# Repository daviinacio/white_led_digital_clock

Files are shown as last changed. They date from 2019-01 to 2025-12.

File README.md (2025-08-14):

# White Led Digital Clock

A digital clock made by scratch. Initially built with cardboard, it was re-assembled with 3D-printed parts. It also received hardware and software improvements. Its based on Arduino UNO microcontroller, assembled in a custom standalone PCB.

| | |
| :---: | :---: |
|  |  |

## Dependencies

- [Arduino Thread](https://github.com/ivanseidel/ArduinoThread)
- [arduino-buffer](https://github.com/daviinacio/arduino-buffer)
- [RTClib](https://github.com/adafruit/RTClib)
- [DHT Sensor Library](https://github.com/adafruit/DHT-sensor-library)
- [Arduino-IRremote](https://github.com/z3t0/Arduino-IRremote)
- [EEPROMEx](https://github.com/thijse/Arduino-EEPROMEx)

## Hardware

- Custom electronic board
- RTC (Real Time Clock)
- DHT (Temperature and Humidity Sensor)
- LDR (Light Dependent Resistor
- IR (Infra Red Receiver)
- Lithium battery
- Buzzer

## Features

- Show the current time
- Show the average of temperature and humidity
- Changes the display brightness automatically
- Can be controlled by TV remote control
- Time adjust
- Adjustable RTC Time Fix

## Files and Images

### Principal files

- [firmware.ino](https://github.com/daviinacio/White_Led_Digital_Clock/blob/master/firmware/firmware.ino)

### Schematic design and PCB prints

|                       Schematic design                        |
| :-----------------------------------------------------------: |
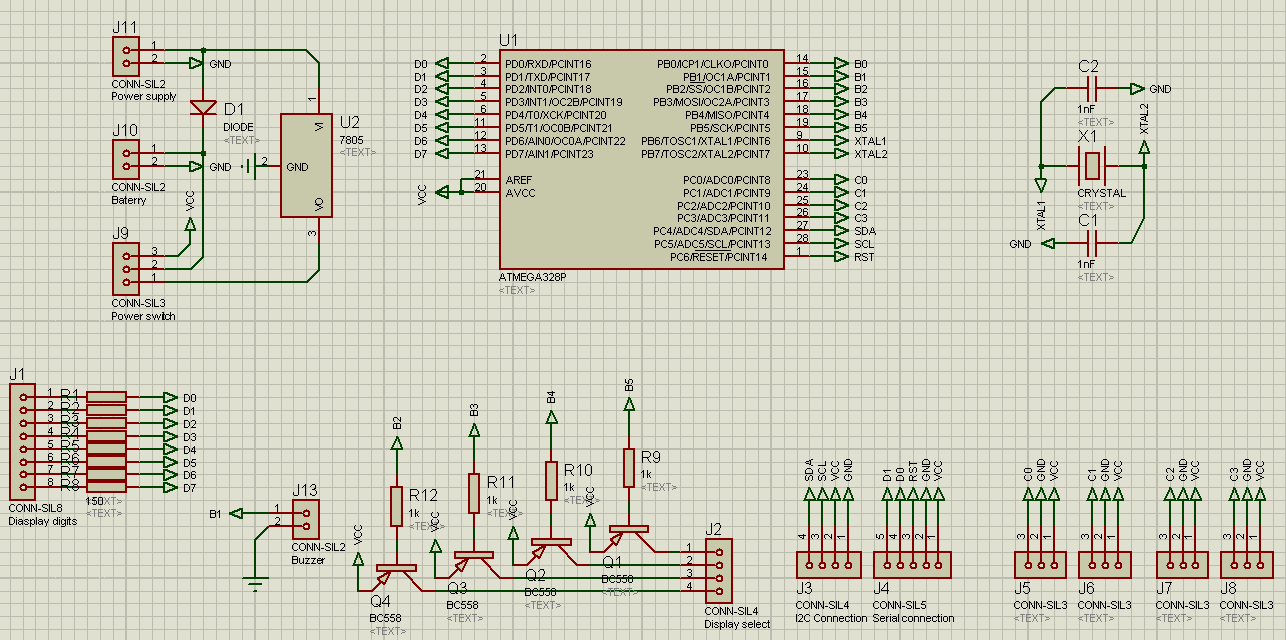
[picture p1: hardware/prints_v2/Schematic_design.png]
Schematic design
|  |

| PCB layout | PCB preview |
| :---: | :---: |
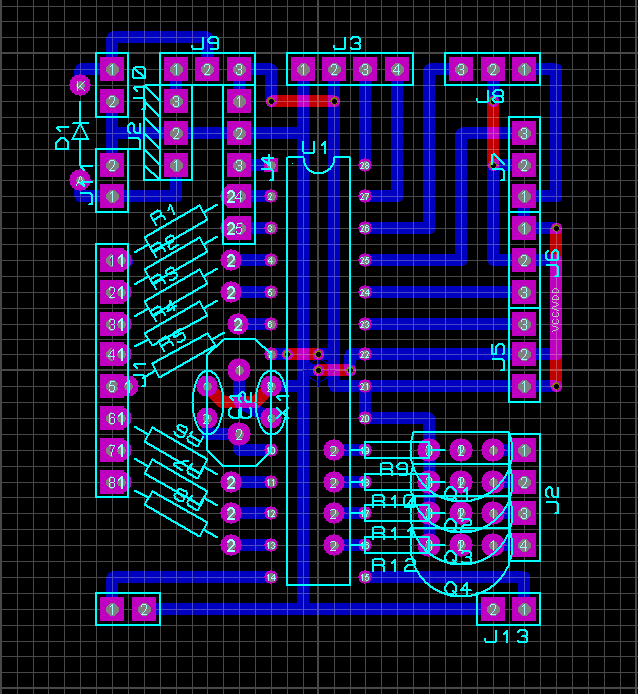
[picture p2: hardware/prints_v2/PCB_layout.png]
PCB layout
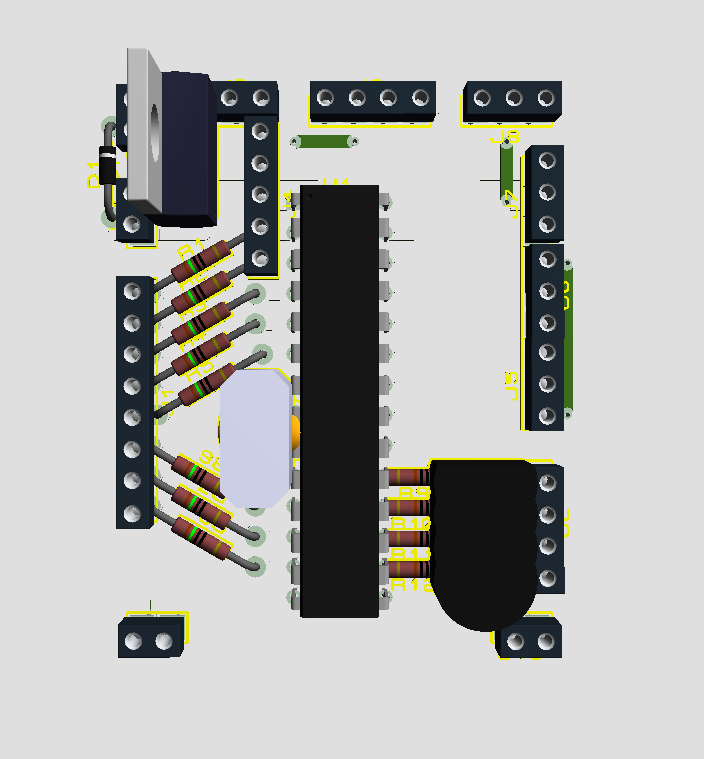
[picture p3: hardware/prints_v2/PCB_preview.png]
PCB preview
|  |  |

### More Photos

| | | |
| :---: | :---: | :---: |
|  |  |  |

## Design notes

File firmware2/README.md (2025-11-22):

# White Led Digital Clock : Firmware v2

## Commands

**Compile**

```bash
pio run
```

**Upload**

```bash
pio run --target upload
```

```bash
pio run -t upload -e <env_name>
```

```bash
pio run -t upload -e uno
```

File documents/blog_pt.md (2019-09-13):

# White Led Digital Clock
#### 01 de maio de 2019

#### OBS: As especificações do projeto podem ser modificadas no futuro.

A estrutura desse projeto foi feita com papelão e sucata.
---------------------------------------------------------------------------------------------------
## Software
- [Firmware](https://github.com/daviinacio/White_Led_Digital_Clock/blob/master/firmware/firmware.ino)

### Dependências
- [Arduino Thread](https://github.com/ivanseidel/ArduinoThread)
- [arduino-buffer](https://github.com/daviinacio/arduino-buffer)
- [RTClib](https://github.com/adafruit/RTClib)
- [Arduino-IRremote](https://github.com/z3t0/Arduino-IRremote)
---------------------------------------------------------------------------------------------------
## Hardware
- Papelão
- Painel Difusor de TV led (Ou qualquer superfície semi-transparente)
- Cola-quente
- Fita crepe
- Fita isolante
- Fita dupla-face

### Fixação
-  2x Porca (#1)
-  4x Porca (#2)
-  2x Parafuso(#1)
-  1x Barra rosqueada (#2)
-  4x Arruela (#1)
-  8x Arruela (#2)

### Componentes Eletrônicos
- 28x [Led SMD Branco 0.5W](http://www.institutodigital.com.br/pd-31c54f-led-smd-branco-0-5w-40-65lm-mod-5730.html)
-  1x [Atmega 328p](http://www.institutodigital.com.br/pd-5666bf-microcontrolador-atmega328p-pu.html)
-  1x [Cristal Ocilador 16MHz](https://www.soldafria.com.br/cristal-16-mhz-meia-caneca-hc49s-p-1940.html)
-  2x [Capacitor cerâmico 22pF](https://www.soldafria.com.br/capacitor-disco-ceramico-22pf-x-50v-npo)
-  8x [Resistor 1/4W 75r](https://www.soldafria.com.br/resistor-de-75r-carbono-5-14w-rxvdptdr-p-112.html)
-  4x [Resistor 1/4W 1k2](https://www.soldafria.com.br/resistor-de-1k2-carbono-5-14w-mrvmvmdr-p-141.html)
-  4x [Transistor BC548](https://www.soldafria.com.br/transistor-bc548b)
-  2x [Barra de pinos 1x40 vias 90 graus](https://www.soldafria.com.br/barra-de-pinos-1x40-vias-17mm-90-graus-p-4033.html)
-  1x [Diodo 1N4007](https://www.soldafria.com.br/diodo-1n4007)
-  1x [LM7805](https://www.soldafria.com.br/circuito-integrado-lm7805-p-557.html)
-  1x [LDR 5mm](http://www.institutodigital.com.br/pd-182de8-sensor-fotoresistor-ldr-5528-de-5mm.html)
-  1x [Receptor Infravermelho](http://www.institutodigital.com.br/pd-182dbd-receptor-universal-infravermelho-vs1838b-38khz.html)
-  1x [Buzzer 5v Ativo](http://www.institutodigital.com.br/pd-2d108d-buzzer-5-volts-ativo.html)
-  1x [Jack J4 DC-005](https://www.soldafria.com.br/jack-j4-dc-005-p-placa-25mm-x-55mm-p-748.html)

### Módulos
- [DHT11](http://www.institutodigital.com.br/pd-f5840-sensor-de-umidade-e-temperatura-dht11.html)
- [RTC DS1307](http://www.institutodigital.com.br/pd-f660a-modulo-real-time-clock-rtc-ds1307.html)

### Adicional
- Bateria de lithium 3.7v
---------------------------------------------------------------------------------------------------
## Contrução

### 1 - Defina as dimensões do display
|Calculos das dimensões|
|----------------------|
||

- 1.1 Baixe e imprima o [modelo de display 7 segmentos](https://github.com/daviinacio/White_Led_Digital_Clock/blob/master/documents/7%20Segment%20Display%20model%20(16cm%20x%208cm).docx)
- 1.2 Una as partes do modelo simetricamente

### 2 - Monte a parte fronta do display
|Calculos das dimensões|
|----------------------|
||

- 2.1 Faça a marcação no papelão à partir do modelo
- 2.2 Corte papelão e fixe o formato com fita crepe

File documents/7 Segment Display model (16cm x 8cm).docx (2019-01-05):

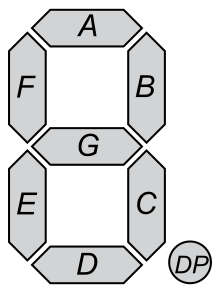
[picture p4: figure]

]b

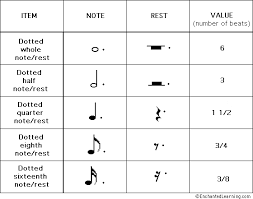
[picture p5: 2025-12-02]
documents/images.png

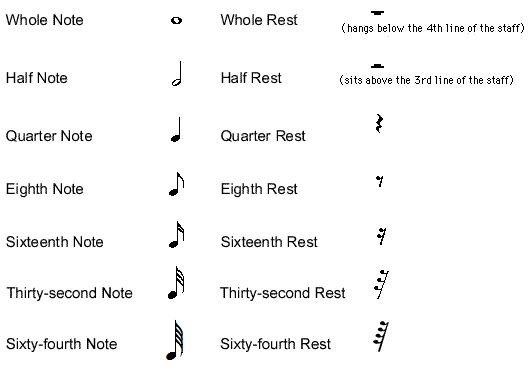
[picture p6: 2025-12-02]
documents/a3cd8b3504482aad7ffb78c6925b5304.jpg

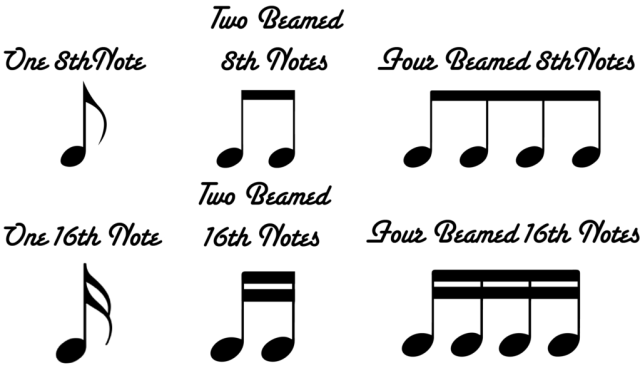
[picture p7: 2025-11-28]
documents/Difference-Between-8th-notes-and-16th-notes-1024x588.webp

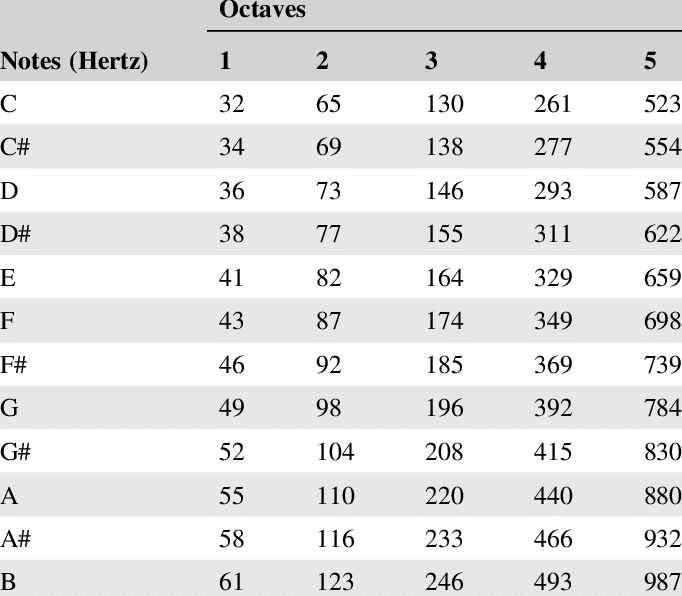
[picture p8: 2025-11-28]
documents/Frequencies-of-musical-notes (1).png

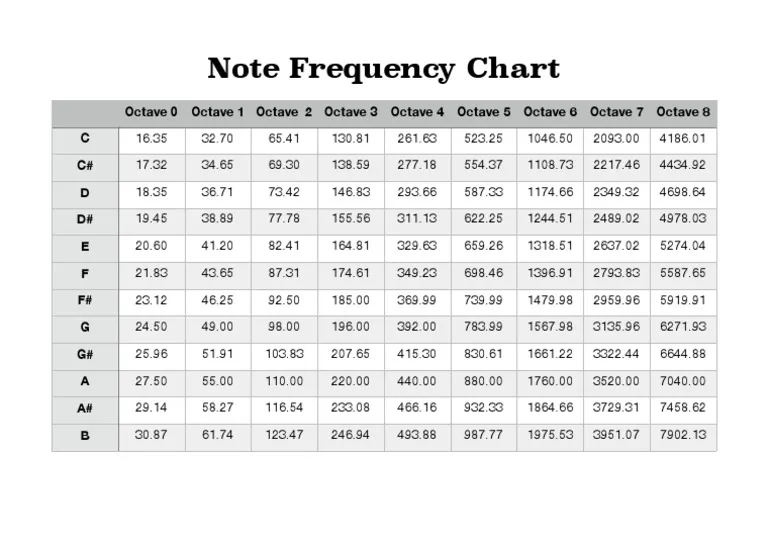
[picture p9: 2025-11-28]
documents/Frequencies-of-musical-notes (2).webp

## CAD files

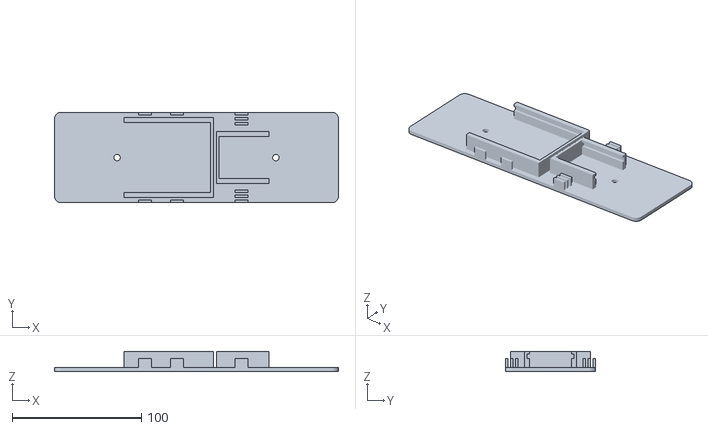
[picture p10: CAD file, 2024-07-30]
3d models/Circuit Platform.stl
220.0 x 70.0 x 15.5

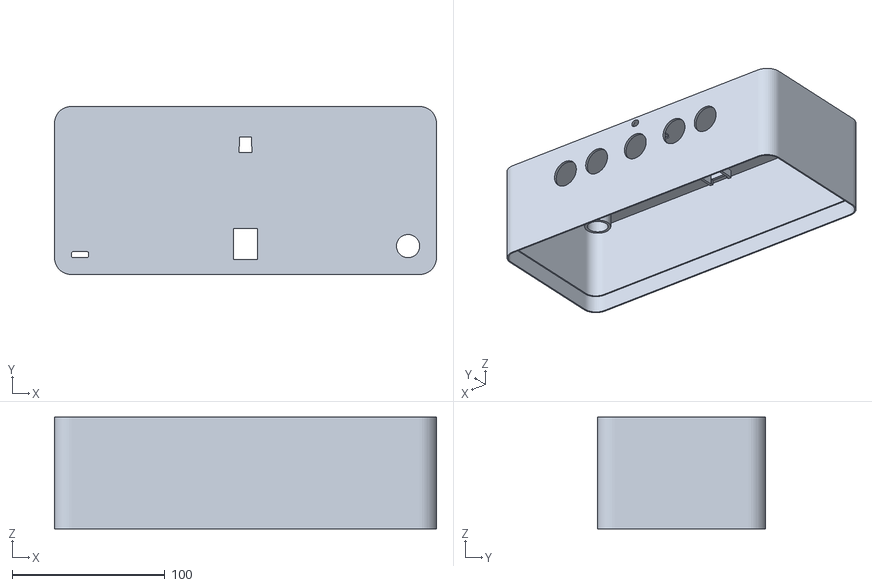
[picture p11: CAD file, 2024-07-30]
3d models/Case.stl
250.0 x 110.0 x 73.0

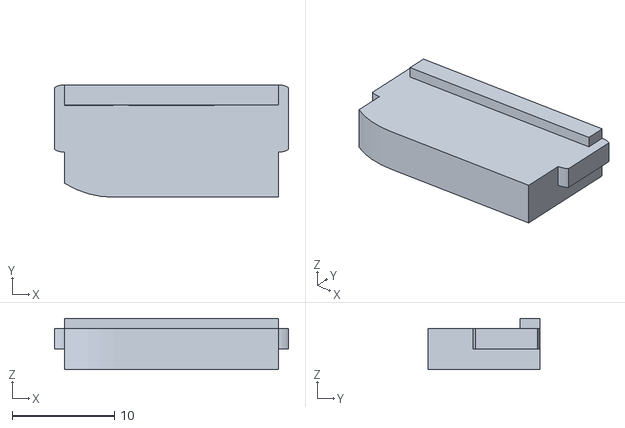
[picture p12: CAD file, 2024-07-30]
3d models/USB-C Slot Lock.stl
22.9 x 11.0 x 5.00

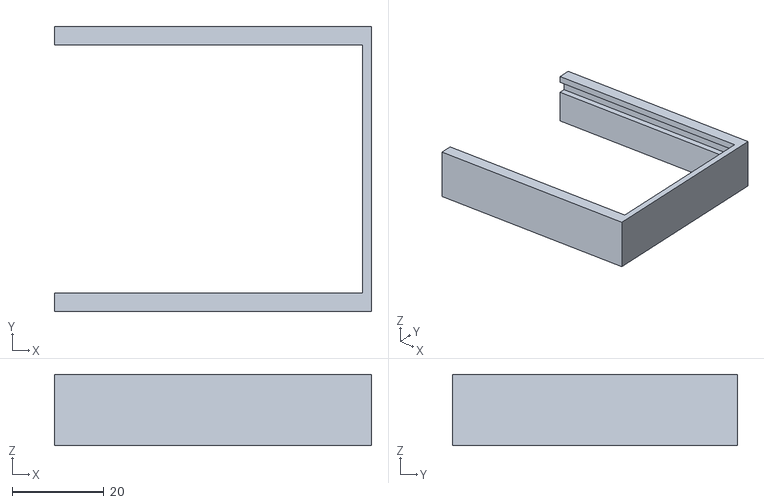
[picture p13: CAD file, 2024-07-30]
3d models/Circuit Platform Supports.stl
69.0 x 62.0 x 15.5

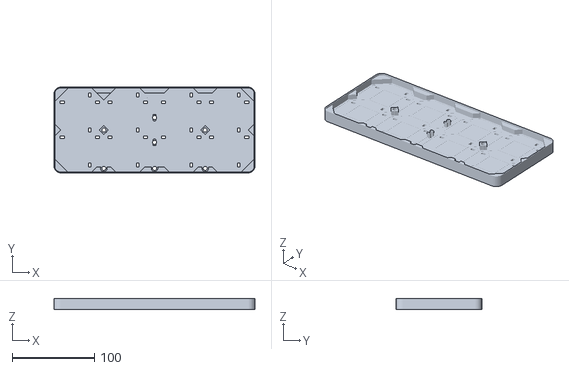
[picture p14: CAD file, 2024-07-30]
3d models/Backlight Front.stl
244.0 x 104.0 x 13.0

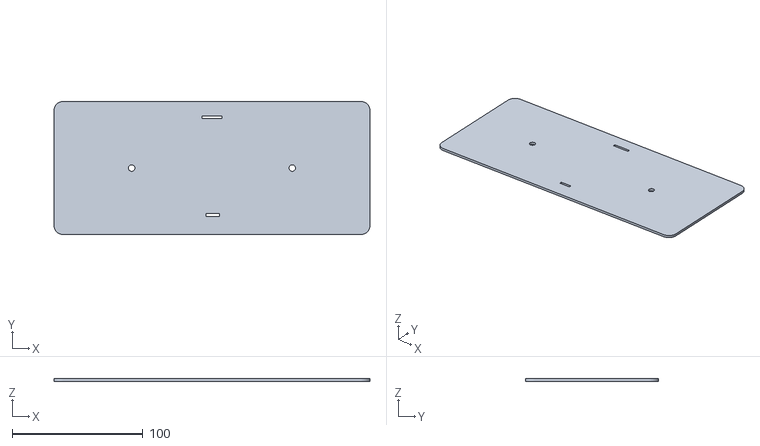
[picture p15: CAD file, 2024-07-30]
3d models/Backlight Back.stl
242.0 x 102.0 x 2.00

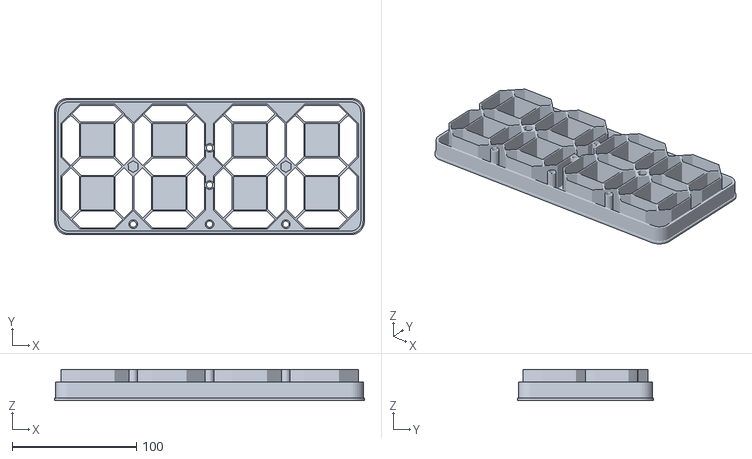
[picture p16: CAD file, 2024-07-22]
3d models/Display.stl
250.0 x 110.0 x 25.0

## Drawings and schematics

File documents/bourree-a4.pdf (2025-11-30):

p

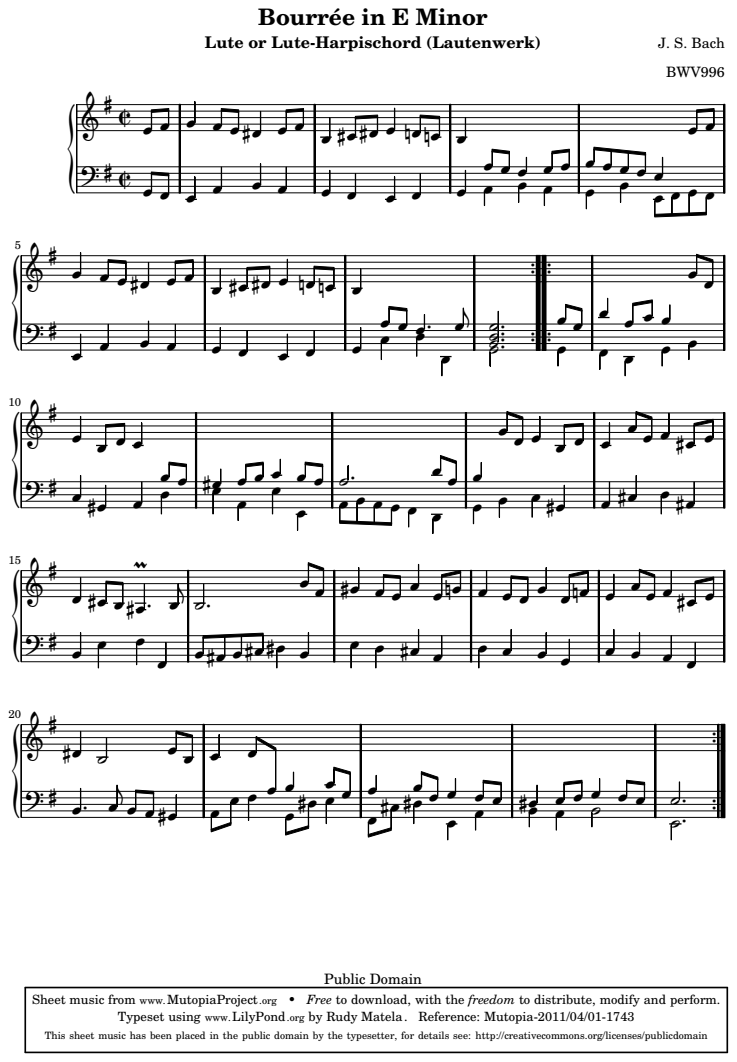
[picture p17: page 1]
Bourrée in E Minor; Lute or Lute-Harpischord (Lautenwerk); J. S. Bach; BWV996; Public Domain

P |    | P

Sheet music from www.MutopiaProject.org • Free to download, with the freedom to distribute, modify and perform.

Typeset using www.LilyPond.org by Rudy Matela. Reference: Mutopia-2011/04/01-1743

This sheet music has been placed in the public domain by the typesetter, for details see: http://creativecommons.org/licenses/publicdomain

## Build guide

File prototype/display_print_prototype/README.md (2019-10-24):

### Compile log before update
```bash
Sketch uses 13828 bytes (42%) of program storage space. Maximum is 32256 bytes.
Global variables use 725 bytes (35%) of dynamic memory, leaving 1323 bytes for local variables. Maximum is 2048 bytes.
```

### Compile log after update
```bash
Sketch uses 13968 bytes (43%) of program storage space. Maximum is 32256 bytes.
Global variables use 780 bytes (38%) of dynamic memory, leaving 1268 bytes for local variables. Maximum is 2048 bytes.
```

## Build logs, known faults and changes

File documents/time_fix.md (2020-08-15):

# Time increase fix
daviinacio | 11/03/2020

## Getting information
> Before check
20h17	20h20	> 3min

> Clock changes
20h18	20h20	> 2min

		26s		> Interval between changes

> Real time changes
20h18	20h21	> 2m26s

Increased 146 seconds in 11 days and 286 seconds (967560 seconds or 967560000 milliseconds)

## Interval calc
```
/* Time in milliseconds */

increased = 146000; 
period = 967560000;

interval = increased / period;

// interval = 6627
```

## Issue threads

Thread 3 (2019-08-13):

Refactor the chronometer display algorithm

daviinacio, 2019-08-13:
The pow functions brake a lot the time machine.
Reducing the call to this function, the code will runs more efficiently.

Change this:
``` C
case MAIN_SCREEN_CHRONOMETER:
  // Put the last digits of number on the display content array
  for(int i = 0; i < DISP_LENGTH; i++)
  disp_content[i] = ((chronometer_counter / (int) pow(10, DISP_LENGTH - i - 1)) % 10) > 0 || chronometer_counter >= (int) pow(10, DISP_LENGTH - i) || (chronometer_counter == 0 && i == DISP_LENGTH - 1) ? seven_seg_numbers[(chronometer_counter / (int) pow(10, DISP_LENGTH - i - 1)) % 10] : 0x00;
  break;
```

To
``` C
case MAIN_SCREEN_CHRONOMETER:
  // Put the last digits of number on the display content array
  for(int i = 0; i < DISP_LENGTH; i++){
    int power = (int) pow(10, DISP_LENGTH - i - 1);
    disp_content[i] = ((chronometer_counter / power) % 10) > 0 || chronometer_counter >= (power * 10) || (chronometer_counter == 0 && i == DISP_LENGTH - 1) ? seven_seg_numbers[(chronometer_counter / power) % 10] : 0x00;
  }
  break;
```

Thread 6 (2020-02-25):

Time increasing on wrong speed

daviinacio, 2020-02-25:
#Time increasing seven seconds everyday.

## Try to solve
- Make a thread to back seven seconds each 24h or one seconds each 3/5 hours
- Seach to hardware fix

Closed 2020-08-15.

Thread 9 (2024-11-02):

Fix panel multiple clicks programmatically.

daviinacio, 2024-11-02:
**Problems**
- The buttons are been presses many time on a single pressing.
- Sometimes, it are reading different button on a single pressing because of button resistance.

**Solutions**
- [ ] Implement a could down after release a button.
- [ ] Ignore if pressing another button without releasing the previous one.

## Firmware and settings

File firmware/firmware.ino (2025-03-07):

/*
 * (c) daviapps 2020
 * 
 * White LED Digital Clock 
 * 
 * description: This is the firmware of a led digital clock (7 segments)
 * author: github.com/daviinacio
 * date: 16/01/2019
 * 
 */

// Disables multiplex display, and enables Serial print
bool debug_mode = false;

#define WAKE_PIN A1

#define LDR_PIN A2
#define LDR_MIN 0
#define LDR_MAX 650

#define DISP_BR_MIN 1
#define DISP_BR_MAX 64

#define DISP_BR_BUFFER_LENGTH 16
#define DISP_BR_BUFFER_INTERVAL 2000
#define DISP_BRINK_INTERVAL 300

#define MAIN_INTERVAL 100
#define MAIN_SCREEN_HOME 0x00
#define MAIN_SCREEN_CHRONOMETER 0x01
#define MAIN_SCREEN_LDR 0x02
#define MAIN_SCREEN_ADJUST_TIME 0x03
#define MAIN_SCREEN_ADJUST_RTC_FIX 0x04

#define MAIN_SCREEN_FIRST MAIN_SCREEN_CHRONOMETER
#define MAIN_SCREEN_LAST MAIN_SCREEN_ADJUST_RTC_FIX

#define CHRONOMETER_INTERVAL 100

#define RTC_INTERVAL 1000

#define DHT_INIT_VALUE -255
#define DHT_PIN A0
#define DHT_TYPE DHT11
#define DHT_BUFFER_LENGTH 4
#define DHT_BUFFER_INTERVAL 60000

#define IR_PIN A1
#define IR_INTERVAL 200

#define BZ_PIN PB1
#define BZ_INTERVAL 62
#define BZ_STATUS_OFF 0x00
#define BZ_STATUS_OLDCLOCK 0x01

#define PANEL_PIN A3
#define PANEL_INTERVAL 100
#define PANEL_LONG_PRESS 8

#define ADJUST_TIME_CURSOR_RANGE 5
#define ADJUST_RTC_FIX_CURSOR_RANGE 2

#define RTC_FIX_INTERVAL_EEPROM_ADDRESS 0x05
#define RTC_FIX_OPERATION_EEPROM_ADDRESS 0x01

// Library imports
#include <EEPROMex.h>
#include <Thread.h>
#include <ThreadController.h>
#include <Wire.h>
#include <avr/sleep.h>

#include "RTClib.h"
#include "DHT.h"

// Import Modules
#include "display.hpp"
#include "panel.hpp"
#include "infrared.hpp"
#include "utils.hpp"
#include "buffer.hpp"

// Modules
AnalogPanel panel = AnalogPanel(PANEL_PIN, PANEL_INTERVAL);
InfraredSensor ir = InfraredSensor(IR_PIN);
// LightSensor ldr = LightSensor(LDR_PIN);


// Threads
ThreadController cpu = ThreadController();
Thread thr_main = Thread();
Thread thr_chronometer = Thread();

Thread thr_ldr = Thread();
Thread thr_rtc = Thread();
Thread thr_dht = Thread();
// Thread thr_ir = Thread();
Thread thr_buzzer = Thread();
Thread thr_rtc_fix = Thread();

Buffer disp_brightness_buffer(DISP_BR_BUFFER_LENGTH, DISP_BR_MAX);

// RTC
RTC_DS1307 rtc;
DateTime rtc_now;

// DHT
DHT dht(DHT_PIN, DHT_TYPE);

Buffer dht_temp_buffer(DHT_BUFFER_LENGTH, DHT_INIT_VALUE);
Buffer dht_hum_buffer(DHT_BUFFER_LENGTH, DHT_INIT_VALUE);

// Main
unsigned short main_current_screen = MAIN_SCREEN_HOME;
unsigned short main_cursor = 0;
bool main_cursor_blink = false;

// Chronometer
unsigned int chronometer_counter = 0;

// Buzzer
unsigned short buzzer_status = BZ_STATUS_OFF;

// RTC Fix
unsigned short rtc_fix_interval = 1;
unsigned short rtc_fix_operation = 1;

// Time Adjust
unsigned short time_adjust_year = 0;
unsigned short time_adjust_month = 0;
unsigned short time_adjust_day = 0;
unsigned short time_adjust_hour = 0;
unsigned short time_adjust_minute = 0;
unsigned short time_adjust_second = 0;

DateTime rtc_adjust;

void setup() {
  /*    *    *  THREADS  *    *    */

  // ldr.onRun(Display.run());

  // Initialize threads
  thr_main.onRun(thr_main_func);
  thr_main.setInterval(MAIN_INTERVAL);

  thr_chronometer.onRun(thr_chronometer_func);
  thr_chronometer.setInterval(CHRONOMETER_INTERVAL);
  thr_chronometer.enabled = false;

  thr_ldr.onRun(thr_ldr_func);
  thr_ldr.setInterval(DISP_BR_BUFFER_INTERVAL / DISP_BR_BUFFER_LENGTH);

  thr_rtc.onRun(thr_rtc_func);
  thr_rtc.setInterval(RTC_INTERVAL);

  thr_dht.onRun(thr_dht_func);
  thr_dht.setInterval(DHT_BUFFER_INTERVAL / DHT_BUFFER_LENGTH);

  // thr_ir.onRun(thr_ir_func);
  // thr_ir.setInterval(IR_INTERVAL);

  thr_buzzer.onRun(thr_buzzer_func);
  thr_buzzer.setInterval(BZ_INTERVAL);

  thr_rtc_fix.onRun(thr_rtc_fix_func);
  thr_rtc_fix.setInterval((uint32_t) rtc_fix_interval * 1000);

  // Add thread to thread controller
  cpu.add(&thr_main);
  cpu.add(&thr_chronometer);
  cpu.add(&thr_rtc);
  cpu.add(&thr_ldr);
  cpu.add(&thr_dht);
  // cpu.add(&thr_ir);
  cpu.add(&ir);
  cpu.add(&thr_buzzer);
  cpu.add(&thr_rtc_fix);

  // Add modules to thread controller
  cpu.add(&panel);
  cpu.add(&Display);
  // cpu.add(&ldr);
  
  /*    *  LIBRARY BEGINNERS  *    */
  Wire.begin();
  dht.begin();
  ir.begin();
  // IrReceiver.begin(IR_PIN);
  //ir_recv.enableIRIn();
  
  if(debug_mode){
    Serial.begin(9600);
    delay(50);
    Serial.println("debug_mode mode initialized");
  }

  Display.begin();

  // Wait for RTC begin
  while(!rtc.begin()){
    // Blink error for five seconds
    if(millis()/500 % 3 >= 1){
      Display.setCursor(0);
      Display.print(F("ERRO"));
    } else {
      Display.clear();
    }
  }

  /*    *    MODULE EVENTS    *    */

  panel.onKeyDown(onKeyDown);
  panel.onKeyPress(onKeyPress);
  panel.onKeyUp(onKeyUp);
  
  ir.onKeyDown(onKeyDown);
  ir.onKeyPress(onKeyPress);
  ir.onKeyUp(onKeyUp);

  /*    *   CHECK COMPONENTS  *    */

  if (!rtc.isrunning()) {
    // Reset time
    rtc.adjust(DateTime(__DATE__, __TIME__));

    // Goto time adjust screen
    main_current_screen = MAIN_SCREEN_ADJUST_TIME;
    main_cursor = 1;
    thr_rtc.enabled = false;
    thr_rtc_fix.enabled = false;
  }

  /*    *     EEPROM READ     *    */
  
  if(EEPROM.isReady()){
    rtc_fix__read();

    if(rtc_fix_interval == 0 && main_current_screen == MAIN_SCREEN_HOME) {
      // Goto rtc fix adjust screen
      main_current_screen = MAIN_SCREEN_ADJUST_RTC_FIX;
      main_cursor = 0;
      thr_rtc.enabled = false;
      thr_rtc_fix.enabled = false;
    }
    else
    if(rtc_fix_interval >= 1){
      thr_rtc_fix.setInterval((uint32_t) rtc_fix_interval * 1000);
    }
  }

  /*    *   THREAD FIRST RUN  *    */
  
  thr_ldr_func();
  thr_rtc_func();
  // thr_dht_func();

  /*    *     END OF BOOT     *    */

  if(debug_mode){
    Display.disable();
  }
  else {
    Display.enable();
  }

  if(!debug_mode){
    Display.clear();
    Display.setCursor(0);
    Display.print(F("DAVI"));
  }

  disp_brightness_buffer.fill(DISP_BR_MAX);
}

void loop() {
  // Run the main thread controller
  cpu.run();
}

void wake() {
  
}

void sleep(){
  // Fake sleep
  cpu.enabled = false;
  Display.disable();

  while(analogRead(PANEL_PIN) > 200);

  cpu.enabled = true;
  Display.enable();

  // static byte prevADCSRA = ADCSRA;
  // ADCSRA = 0;

  // set_sleep_mode(SLEEP_MODE_STANDBY);
  // sleep_enable();

  // MCUCR = bit(BODS) | bit(BODSE);
  // MCUCR = bit(BODS);

  // noInterrupts();
  // attachInterrupt(digitalPinToInterrupt(WAKE_PIN), wake, LOW);
  // interrupts();

  // sleep_cpu();

  // wake();

  // ADCSRA = prevADCSRA;


  
  // // Disable ADC
  // ADCSRA &= ~(1 << 7);

  // // Enable sleep
  // SMCR |= (1 << 2);
  // SMCR |= 1;

  // // Disable BOD
  // MCUCR |= (3 << 5);
  // MCUCR |= (MCUCR & ~(1 << 5)) | (1 << 6);
  // __asm__ __volatile__("sleep");
}

/*    *    *    *    MODULES   *    *    *    */
void onKeyDown(InputKey key){
  // Cooldown
  if(!panel.isIdle(200)) return;

  if(debug_mode){
    Serial.print(F("onKeyDown: Key "));
    Serial.println((int) key);
  }

  if(main_current_screen == MAIN_SCREEN_HOME || main_current_screen == MAIN_SCREEN_LDR) {
    if(key == KEY_VALUE_UP)
      disp_brightness_up();
    else if(key == KEY_VALUE_DOWN)
      disp_brightness_down();

    if(main_current_screen != MAIN_SCREEN_HOME)
      return;

    if(key == KEY_FUNC_RIGHT)
      increment(main_cursor, 0, 2, false);
    else if(key == KEY_FUNC_LEFT)
      decrement(main_cursor, 0, 2, false);
  }
  else if(main_current_screen == MAIN_SCREEN_CHRONOMETER){
    if(key == KEY_VALUE_UP)
      thr_chronometer.enabled = !thr_chronometer.enabled;
    else if(key == KEY_VALUE_DOWN){
      if(thr_chronometer.enabled)
        thr_chronometer.enabled = false;
      else
        chronometer_counter = 0;
    }
  }
  else if(main_current_screen == MAIN_SCREEN_ADJUST_TIME){
    if(key == KEY_FUNC_LEFT)
      increment(main_cursor, 0, 4, false);
    else if(key == KEY_FUNC_RIGHT)
      decrement(main_cursor, 0, 4, false);

    screen_adjust_time__handler(key);
  }
  else if(main_current_screen == MAIN_SCREEN_ADJUST_RTC_FIX){
    if(key == KEY_FUNC_LEFT)
      increment(main_cursor, 0, 1, false);
    else if(key == KEY_FUNC_RIGHT)
      decrement(main_cursor, 0, 1, false);

    screen_adjust_rtc_fix__handler(key, 1);
  }
}

void onKeyPress(InputKey key, unsigned int milliseconds){
  int time = milliseconds / PANEL_INTERVAL;

  if(debug_mode){
    Serial.print(F("onKeyPress: Key "));
    Serial.print((int) key);
    Serial.print(F(", "));
    Serial.print((int) milliseconds);
    Serial.println(F("ms"));
  }

  if(main_current_screen == MAIN_SCREEN_HOME || main_current_screen == MAIN_SCREEN_LDR) {
    if((key == KEY_VALUE_UP || key == KEY_VALUE_DOWN) && time == PANEL_LONG_PRESS)
      disp_brightness_auto();
  }
  else if(main_current_screen == MAIN_SCREEN_ADJUST_TIME && time > PANEL_LONG_PRESS)
    screen_adjust_time__handler(key);
  else if(main_current_screen == MAIN_SCREEN_ADJUST_RTC_FIX && time > PANEL_LONG_PRESS)
    screen_adjust_rtc_fix__handler(key, time / 2);

  // Home button long press
  if(key == KEY_HOME && time == PANEL_LONG_PRESS) {
    if(main_current_screen == MAIN_SCREEN_HOME && !Display.isScrolling()){
      Display.setTimeSeparator(false);
      Display.printEnd(F("*__*")); delay(750);
      Display.printEnd(F("-__-")); delay(150);
      Display.printEnd(F("*__*")); delay(500);
      Display.printEnd(F("-__-")); delay(500);
      Display.clear();
      delay(250);

      sleep();

      Display.printEnd(F("-__-")); delay(750);
      Display.printEnd(F("*__*")); delay(250);
      Display.printEnd(F("-__-")); delay(150);
      Display.printEnd(F("*__*")); delay(500);
      Display.printEnd(F("*__-")); delay(500);
      Display.printEnd(F("*__*")); delay(500);
      
    }
    else {
      main_screen_destroy();
      main_current_screen = MAIN_SCREEN_HOME;
      main_cursor = 0;

      Display.clearScroll();
      Display.setCursor(0);
      Display.print(F("----"));
      Display.printScroll(F("----"), 1000);
    }
  }
}

void onKeyUp(InputKey key, unsigned int milliseconds){
  int time = milliseconds / PANEL_INTERVAL;

  if(debug_mode){
    Serial.print(F("onKeyUp: Key "));
    Serial.print((int) key);
    Serial.print(F(", "));
    Serial.print((int) milliseconds);
    Serial.println(F("ms"));
  }

  if(time >= PANEL_LONG_PRESS) return;

  if(Display.isScrolling() || (main_current_screen == MAIN_SCREEN_HOME && main_cursor == 0)) {
    if(key == KEY_HOME){
      main_screen_destroy();
      increment(main_current_screen, MAIN_SCREEN_FIRST, MAIN_SCREEN_LAST, true);

      main_screen_initialize();
    }
    return;
  }
  else if(key == KEY_HOME){
    if(main_current_screen == MAIN_SCREEN_ADJUST_TIME)
      screen_adjust_time__submit();
    else if(main_current_screen == MAIN_SCREEN_ADJUST_RTC_FIX)
      screen_adjust_rtc_fix__submit();
    else {
      Display.clearScroll();
    }

    main_screen_destroy();
    main_current_screen = MAIN_SCREEN_HOME;
    main_cursor = 0;
    return;
  }

  if(main_current_screen == MAIN_SCREEN_ADJUST_TIME){
    // main_cursor_blink = true;
  }
}

void main_screen_initialize(){
  print_current_screen_name();

  if(main_current_screen != MAIN_SCREEN_HOME)
    main_cursor = 0;

  if(main_current_screen == MAIN_SCREEN_ADJUST_TIME) 
    screen_adjust_time__initialize();
  else if(main_current_screen == MAIN_SCREEN_ADJUST_RTC_FIX)
    screen_adjust_rtc_fix__initialize();
}

void main_screen_destroy(){
  if(main_current_screen == MAIN_SCREEN_ADJUST_TIME)
    screen_adjust_time__destroy();
  else if(main_current_screen == MAIN_SCREEN_ADJUST_RTC_FIX)
    screen_adjust_rtc_fix__destroy();
}

void print_current_screen_name(){
  Display.clearScroll();
  switch(main_current_screen){
    case MAIN_SCREEN_LDR: Display.printScroll(F("    BRILHO    "), 150); break;
    case MAIN_SCREEN_CHRONOMETER: Display.printScroll(F("    CRONOMETRO    "), 150); break;
    case MAIN_SCREEN_ADJUST_TIME: Display.printScroll(F("    SET TIME    "), 150); break;
    case MAIN_SCREEN_ADJUST_RTC_FIX: Display.printScroll(F("    RTC FIX    "), 150); break;
  }
}


/*    *    *      SCREEN EVENTS     *    *    */
void screen_adjust_time__initialize(){
  rtc_now = rtc.now();
  time_adjust_year = rtc_now.year();
  time_adjust_month = rtc_now.month();
  time_adjust_day = rtc_now.day();
  time_adjust_hour = rtc_now.hour();
  time_adjust_minute = rtc_now.minute();
  // main_cursor_blink = true;

  thr_rtc_fix.enabled = false;
  thr_rtc.enabled = false;
}

void screen_adjust_time__destroy(){
  thr_rtc_fix.enabled = true;
  thr_rtc.enabled = true;
}

void screen_adjust_time__handler(InputKey key){
  if(main_cursor == 0) {        // Minute
    if(key == KEY_VALUE_UP)
      increment(time_adjust_minute, 0, 59, true);
    else if(key == KEY_VALUE_DOWN)
      decrement(time_adjust_minute, 0, 59, true);
  }
  else if(main_cursor == 1) {   // Hour
    if(key == KEY_VALUE_UP)
      increment(time_adjust_hour, 0, 23, true);
    else if(key == KEY_VALUE_DOWN)
      decrement(time_adjust_hour, 0, 23, true);
  }
  else if(main_cursor == 2) {   // Day
    if(key == KEY_VALUE_UP)
      increment(time_adjust_day, 1, month_last_day(time_adjust_year, time_adjust_month), true);
    else if(key == KEY_VALUE_DOWN)
      decrement(time_adjust_day, 1, month_last_day(time_adjust_year, time_adjust_month), true);
  }
  else if(main_cursor == 3) {   // Month
    if(key == KEY_VALUE_UP)
      increment(time_adjust_month, 1, 12, true);
    else if(key == KEY_VALUE_DOWN)
      decrement(time_adjust_month, 1, 12, true);

    range(time_adjust_day, 1, month_last_day(time_adjust_year, time_adjust_month));
  }
  else if(main_cursor == 4) {   // Year
    if(key == KEY_VALUE_UP)
      increment(time_adjust_year, 2000, 2038, true);
    else if(key == KEY_VALUE_DOWN)
      decrement(time_adjust_year, 2000, 2038, true);

    range(time_adjust_day, 1, month_last_day(time_adjust_year, time_adjust_month));
  }
}

void screen_adjust_time__submit(){
  rtc.adjust(DateTime(
    time_adjust_year, time_adjust_month, time_adjust_day,
    time_adjust_hour, time_adjust_minute, 0
  ));
  Display.printScroll(F("SAVE"), 1500);
}



void screen_adjust_rtc_fix__initialize(){
  rtc_fix__read();
  thr_rtc_fix.enabled = false;
  thr_rtc.enabled = false;
}

void screen_adjust_rtc_fix__destroy(){
  rtc_fix__read();
  thr_rtc_fix.enabled = true;
  thr_rtc.enabled = true;
}

void screen_adjust_rtc_fix__handler(InputKey key, unsigned short mult){
  if(main_cursor == 0) {        // Interval
    if(key == KEY_VALUE_UP)
      increment(rtc_fix_interval, 1, 9999, false, mult);
    else if(key == KEY_VALUE_DOWN)
      decrement(rtc_fix_interval, 1, 9999, false, mult); 
  }
  else if(main_cursor == 1) {   // Operation
    if(key == KEY_VALUE_UP)
      increment(rtc_fix_operation, 0, 2, false, mult);
    else if(key == KEY_VALUE_DOWN)
      decrement(rtc_fix_operation, 0, 2, false, mult);
  }
}

void screen_adjust_rtc_fix__submit(){
  rtc_fix__write();
  thr_rtc_fix.setInterval((uint32_t) rtc_fix_interval * 1000);
  Display.printScroll(F("SAVE"), 1500);
}

void rtc_fix__read(){
  rtc_fix_operation = EEPROM.readInt(
    RTC_FIX_OPERATION_EEPROM_ADDRESS
  );
  
  rtc_fix_interval = EEPROM.readInt(
    RTC_FIX_INTERVAL_EEPROM_ADDRESS
  );
}

void rtc_fix__write(){
  EEPROM.writeInt(RTC_FIX_INTERVAL_EEPROM_ADDRESS, rtc_fix_interval);
  EEPROM.writeInt(RTC_FIX_OPERATION_EEPROM_ADDRESS, rtc_fix_operation);
}


/*    *    *    *    THREAD    *    *    *    */

void thr_main_func() {
  if(debug_mode){
    // PinMode display digits pins
    PORTD = 0b00000010;                   // Set all PortD pins to HIGH
    PORTB = 0b00111100;              // Set all PortB pins to HIGH
    return;
  }

  if(Display.isScrolling())
    return;

  Display.setTimeSeparator(false);

  long m = millis();
  bool idle = ir.isIdle(2000) && panel.isIdle(2000);
  main_cursor_blink = ir.isIdle(500) && panel.isIdle(1000);
  
  switch(main_current_screen){
    case MAIN_SCREEN_HOME:
      thr_main.setInterval(MAIN_INTERVAL);
    
      // Initial interval
      if(m <= 2000){ /* Do nothing */ } else
      
      // Temperature                  // Each 20s, runs on 16s, per 2s
      if(((m / 2000 % 10 == 8 && main_cursor == 0 && idle) || main_cursor == 1) && dht_temp_buffer.getAverage() != DHT_INIT_VALUE){
        Display.setCursor(0);
        Display.print((int) dht_temp_buffer.getAverage());
        Display.printEnd(F("*C"));
      } else
      
      // Humidity                     // Each 20s, runs on 18s, per 2s
      if(((m / 2000 % 10 == 9 && main_cursor == 0 && idle) || main_cursor == 2) && dht_hum_buffer.getAverage() != DHT_INIT_VALUE){
        Display.clear();
        Display.setCursor(0);
        Display.print(F("H"));
        Display.printEnd(dht_hum_buffer.getAverage());
      }
      
      // Hours and Minutes
      else {                          // Runs when others 'IFs' are false
        Display.setTimeSeparator(thr_rtc.enabled);
        Display.setCursor(0);
        
        if(rtc_now.hour() < 10)
          Display.print(0);
        Display.print(rtc_now.hour());

        if(rtc_now.minute() < 10)
          Display.print(0);
        Display.print(rtc_now.minute());
      }
      break;

    case MAIN_SCREEN_LDR:
      Display.setCursor(0);
      Display.print(F("BR"));

      if(Display.getBrightness() < 10)
        Display.print(F(" "));
      Display.printEnd(Display.getBrightness());
      break;

    case MAIN_SCREEN_CHRONOMETER:
      thr_main.setInterval(CHRONOMETER_INTERVAL);
      Display.clear();

      if(chronometer_counter < 600){
        Display.printEnd(chronometer_counter * 0.1, 1);
      }
      else if(chronometer_counter < 36000) {
        Display.setCursor(0);
        unsigned short minute = (chronometer_counter / 10) / 60;
        unsigned short seconds = (chronometer_counter / 10) % 60;

        if(minute < 10)
          Display.print(F(" "));
        Display.print(minute);

        if(seconds < 10)
          Display.print(0);
        Display.print(seconds);
        
        Display.setTimeSeparator((millis() / 500 % 2 == 1) || !thr_chronometer.enabled);
      }
      else {
        thr_chronometer.enabled = false;
        chronometer_counter = 0;
      }

      break;

    case MAIN_SCREEN_ADJUST_TIME:
      Display.setCursor(0);
    
      if(main_cursor == 0 || main_cursor == 1){  // Minutes & Hours
        Display.setCursor(0);

        if((main_cursor == 1 && millis()/DISP_BRINK_INTERVAL % 3 == 0) && main_cursor_blink){   // Blink 1/3 on focus
          Display.print(F("  "));
        }
        else {
          if(time_adjust_hour < 10)
            Display.print(0);
          Display.print(time_adjust_hour);
        }

        if((main_cursor == 0 && millis()/DISP_BRINK_INTERVAL % 3 == 0) && main_cursor_blink){   // Blink 1/3 on focus
          Display.print(F("  "));
        }
        else {
          if(time_adjust_minute < 10)
            Display.print(0);
          Display.print(time_adjust_minute);
        }
      }
      else
      if(main_cursor == 2){  // Day
        Display.setCursor(0);
        Display.print(F("D "));

        if((millis()/DISP_BRINK_INTERVAL % 3 == 0) && main_cursor_blink){  // Blink 1/3 on focus
          Display.print(F("  "));
        }
        else {
          if(time_adjust_day % 100 < 10)
            Display.print(F(" "));
            
          Display.printEnd(time_adjust_day);
        }
      }
      else
      if(main_cursor == 3){  // Month
        Display.setCursor(0);
        Display.print(F("M "));

        if((millis()/DISP_BRINK_INTERVAL % 3 == 0) && main_cursor_blink){  // Blink 1/3 on focus
          Display.print(F("  "));
        }
        else {
          if(time_adjust_month % 100 < 10)
            Display.print(F(" "));
            
          Display.printEnd(time_adjust_month);
        }
      }
      else
      if(main_cursor == 4){  // Year
        Display.setCursor(0);
        Display.print(F("Y "));

        if((millis()/DISP_BRINK_INTERVAL % 3 == 0) && main_cursor_blink){  // Blink 1/3 on focus
          Display.print(F("  "));
        }
        else {
          if(time_adjust_year % 100 < 10)
            Display.print(F(" "));
            
          Display.printEnd((int) time_adjust_year % 100);
        }
      }
      break;

    case MAIN_SCREEN_ADJUST_RTC_FIX:
      if(main_cursor == 0){  // Interval
        Display.clear();
        Display.setCursor(0);
        
        if(!((millis()/DISP_BRINK_INTERVAL % 3 == 0) && main_cursor_blink)){  // Blink 1/3 on focus
          Display.printEnd(rtc_fix_interval);
        }
      }
      else
      if(main_cursor == 1){ // Opetarion
        Display.setCursor(0);
        Display.print(F("OP "));
        
        if((millis()/DISP_BRINK_INTERVAL % 3 == 0) && main_cursor_blink){  // Blink 1/3 on focus
          Display.print(F(" "));
        }
        else {
          Display.printEnd(rtc_fix_operation);
        }
      }
      break;

    default:
      Display.clear();
      Display.setCursor(0);
      Display.print(F("MERR"));
      break;
  }
}

void thr_chronometer_func(){
  chronometer_counter++;
  chronometer_counter %= (int) pow(10, DISP_LENGTH);
}

void thr_ldr_func(){
  // Make the ldr sensor read
  int br_read = map(analogRead(LDR_PIN), LDR_MIN, LDR_MAX, DISP_BR_MIN, DISP_BR_MAX);

  // Avoid out of range problems
  if(br_read > DISP_BR_MAX) br_read = DISP_BR_MAX; else
  if(br_read < DISP_BR_MIN) br_read = DISP_BR_MIN;

  disp_brightness_buffer.insert(br_read);
  Display.setBrightness(disp_brightness_buffer.getAverage());
}

void thr_rtc_func(){
  rtc_now = rtc.now();
}
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

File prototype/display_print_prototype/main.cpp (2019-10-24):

/*
 * (c) daviapps 2019
 *
 * White LED Digital Clock
 *       Prototype
 *
 * description: This is a prototype to make easy to work with the display content
 * author: github.com/daviinacio
 * site: daviinacio.com.br
 * date: 12/09/2019
 *
 */

// To run this on terminal type: ./run

// Abstraction from the real code
#define DISP_LENGTH 4

#include <stdlib.h>
#include <stdio.h>
#include <string.h>
#include <string>
#include <math.h>

using namespace std;

/*
// Seven Segments Display Abstraction

|--- a ---|
|         |
f         b
|         |
|--- g ---|
|         |
e         c
|         |
|--- d ---| (.)

0b [a], [b], [c], [d], [e], [f], [g], [.]
    0    1    2    3    4    5    6    7

*/

using namespace std;


// ASCII map for seven Segments
// TODO: This will will replaced for binary content
unsigned char seven_seg_asciis [((int) 'Z' - '*') + 1] = {
    '*',
    // Especial characters
    0x00, 0x00,
    '-',
    // Especial characters
    0x00, 0x00,

    // Numbers
    '0', '1', '2', '3', '4', '5', '6', '7', '8', '9',
    
    // Especial characters
    0x00, 0x00, 0x00, 0x00, 0x00, 0x00, 0x00,

    // Alfabetic characters
    'A', 'B', 'C', 'D', 'E', 'F', 'G', 'H', 'I', 'J', 'K', 'L', 'M',
    'N', 'O', 'P', 'Q', 'R', 'S', 'T', 'U', 'V', 'W', 'X', 'Y', 'Z'
};
int seven_seg_ascii_init = '*'; // First mapped ascci position

// Content
unsigned char disp_content [DISP_LENGTH];
// Cursor
int disp_content_cursor = 0;

// Debug
void debug_disp_content(){
    //printf("disp_content_cursor = %i\n", disp_content_cursor);
    for(int i = 0; i < DISP_LENGTH; i++)
        printf("[%c]", disp_content[i]);
    
    printf("\n\n");
}

// Prototype
void disp_setCursor(int col){
    disp_content_cursor = col % DISP_LENGTH;
}

void disp_clear(){
    for(int i = 0; i < DISP_LENGTH; i++)
        disp_content[i] = 0x00;
}

void disp_print(char c){
    disp_content[disp_content_cursor] = seven_seg_asciis[((int) c) - seven_seg_ascii_init]; //content[i];
    disp_content_cursor++;
}

void disp_print(std::string content){
    const char* _content = content.c_str();
    for(int i = 0; i < strlen(_content) && disp_content_cursor < DISP_LENGTH; i++)
        disp_print(content[i]);
}

// void disp_print(char content []){
//     for(int i = 0; i < strlen(content) && disp_content_cursor < DISP_LENGTH; i++)
//         disp_print(content[i]);
// }

// void disp_print(string content){
//     disp_print(content);
// }

void disp_print(int num){
    char _num [11] = "";
    //itoa(num, _num, 10);
    sprintf(_num, "%d", num);
    disp_print(_num);
}

// Print on the end
void disp_printEnd(std::string content){
    const char* _content = content.c_str();

    disp_setCursor(DISP_LENGTH - strlen(_content));
    disp_print(_content);
}

// void disp_printEnd(char content []){
//     disp_setCursor(DISP_LENGTH - strlen(content));
//     disp_print(content);
// }

// void disp_printEnd(string content){
//     disp_printEnd(content);
// }

void disp_printEnd(char c){ 
    disp_setCursor(DISP_LENGTH - 1);
    disp_print(c);
}

void disp_printEnd(int num){
    char _num [11] = "";
    //itoa(num, _num, 10);
    sprintf(_num, "%d", num);

    disp_printEnd(_num);
}


int main(){
    printf("Print string\n");
    disp_clear();
    disp_setCursor(0);
    disp_print("DAVI INACIO");

    debug_disp_content();

    printf("Print per character\n");
    disp_clear();
    disp_setCursor(0);
    
    disp_print('I');
    disp_print('V');
    disp_print('A');
    disp_print('D');

    debug_disp_content();

    printf("Print integer\n");
    disp_clear();
    disp_setCursor(0);
    disp_print(42);

    debug_disp_content();

    printf("Print negative integer\n");
    disp_clear();
    disp_setCursor(0);
    disp_print(-42);

    debug_disp_content();

    printf("******* PRINT ON THE END *******\n\n");

    printf("Print string on the end\n");
    disp_clear();
    disp_printEnd("DI");

    debug_disp_content();

    printf("Print character on the end\n");
    disp_clear();
    disp_printEnd('D');

    debug_disp_content();

    printf("Print integer on the end\n");
    disp_clear();
    disp_printEnd(42);

    debug_disp_content();

    printf("Print negative integer on the end\n");
    disp_clear();
    disp_printEnd(-42);

    debug_disp_content();

    printf("Print diferent Types\n");
    disp_clear();
    disp_setCursor(0);
    disp_print("HUMD");

    disp_printEnd(-42);
    
    debug_disp_content();

    int temp = 7;

    disp_clear();
    disp_setCursor(0);
    disp_print(0);
    disp_setCursor(temp > 0 && temp < 10 ? 1 : 0);
    disp_print(temp);
    disp_print("*C");
    
    debug_disp_content();

    int inp = 0;
    scanf("%i", &inp);
    //system("PAUSE");
}

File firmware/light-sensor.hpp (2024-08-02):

#ifndef WLDC_LIGHT_SENSOR_H
#define WLDC_LIGHT_SENSOR_H
#include <Thread.h>
#include "display.hpp"

#define LDR_DEFAULT_PIN A2
#define LDR_DEFAULT_BUFFER_LENGTH 16
#define LDR_DEFAULT_DURATION 2000

class LightSensor : public Thread {
protected:
  int pin;
  long duration = 0;
public:
  LightSensor();
  LightSensor(int _pin);
  LightSensor(int _pin, unsigned long _duration);
  LightSensor(int _pin, unsigned long _duration, int _buffer_length);
  void run();
};

LightSensor::LightSensor(int _pin, unsigned long _duration, int _buffer_length){
  
}

LightSensor::LightSensor(int _pin, unsigned long _duration) {
  LightSensor(_pin, _duration, LDR_DEFAULT_BUFFER_LENGTH);
}

LightSensor::LightSensor(int _pin){
  LightSensor(_pin, LDR_DEFAULT_DURATION);
}

LightSensor::LightSensor(){
  LightSensor(LDR_DEFAULT_PIN);
}

void LightSensor::run(){
  //Display.setBrightness(0);
}



#endif

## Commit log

2019-01-05 Inital backup
    [white_clock_board.DSN]
2019-01-05 Folder organize
    Make the folders and files look fine
    [white_clock_board.DSN]
2019-01-06 Create the hardware design
    [white_clock_board.DSN, white_clock_board.SDF]
2019-01-06 Printings the PCB and Schematic project
2019-01-17 Board builded and new firmware version stated
    PCB design was modified to be easy to build the real version.
    The firmware v3 was created:
    - ATMEGA TIMER1
    - Buffer on ldr read
    - Brightness control
    [white_clock_board.DSN, white_clock_board.SDF]
2019-01-18 Real Time Clock module implemented
    Real Time Clock library and thread was implemented
2019-01-20 Start to implements DHT
    ISSUE: A stanger conflict beetwen the TIMER1 Multiplexing and the DHT read proccess..
    [firmware.ino]
2019-01-20 DHT implemented
    Multiplex changed to TIMER2
    DHT implemented
    DHT and TIMER conflict solved
    [firmware.ino]
2019-01-21 Content Manage
    Incremented new hex on ir read.
    A best content manage on thread main.
    New controlls via ir receptor
2019-01-25 DHT ignore read erros
    - Not put invalid reads on buffer array
    - Not show dht values, case nothing was readed
2019-03-31 arduino-buffer implemented
    [white_clock_board.SDF]
2019-05-27 Blog post prototype
2019-09-12 display print prototype
2019-09-13 Print integer implemented
2019-09-13 Print on the end implemented
2019-09-14 Display print functions implemented on master\n- Feliz dia do programador\n- Print string\n- Print character\n- Print integer\n Print negative integer\n- Print on the end\n- Text scroll
2020-02-19 Time Adjust prototype
2020-02-19 print char* fix
2020-02-20 Fix to fit on hardware
    [firmware.ino]
2020-03-06 Thread RTC Fix
2020-03-11 Implemented on hardware Interval calculated Fix confict between time-adjust and rtc-fix Calc documentated
    [firmware.ino]
2020-03-17 Hardware update
    [white_clock_board.DSN, white_clock_board.SDF]
2020-03-19 Inversion Fix, Boot blink all Hardware update
    [white_clock_board.DSN]
2020-08-15 Adjustable RTC fix - Save settings on EEPROM
    [firmware.ino]
2024-07-22 3D Modeling
    [Clock v12.stl, Fusion Project.stl]
2024-07-30 3D Modeling, IR remap
    [Backlight Back.stl, Backlight Front.stl, Case.stl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]
2024-07-31 Panel Thread
2024-08-27 Adjust RTC Fix, decrement hotfix, print progmem
    [display.hpp, firmware.ino]
2025-11-28 Play notes on Buzzer, Timer1 Ocillator, MusicPlayer, syncTone, syncPlay
    [Display.cpp]
2026-07-10 Add Pomodoro screen and expand music library
    - Add PomodoroScreen (work/break cycles) with WLDC_SCREEN_POMODORO id;
    Home now navigates to it instead of Chronometer
    - Expand and reorganize music library: new game themes, fx sounds and
    personal tracks; replace marble_machine with the piano version and
    rebuild all.hpp / MusicScreen list
    - Music engine: double timing resolution (WHOLE_NOTE_TIMING_TICKS 64->128),
    mute buzzer on playback finish, drop dead next_* helpers, include
    <Arduino.h> in base.h
    - Replace magic navigate(1) calls with WLDC_SCREEN_HOME
    - Disable DHT and boot to Home screen
2026-07-10 Optimize sonic_greenhill; rework music playlist and portal track
    - Optimize sonic_greenhill (requantize timings + factor consecutive
    repeats), playback-identical: 2598->1036 B of sheet data, firmware
    flash 95.8%->90.9%
    - Rename portal_still_alive_acoccimi -> portal_still_alive and drop
    the old still_alive variant
    - Reorder MusicScreen playlist and enable greenhill, undertale and
    stranger_things
